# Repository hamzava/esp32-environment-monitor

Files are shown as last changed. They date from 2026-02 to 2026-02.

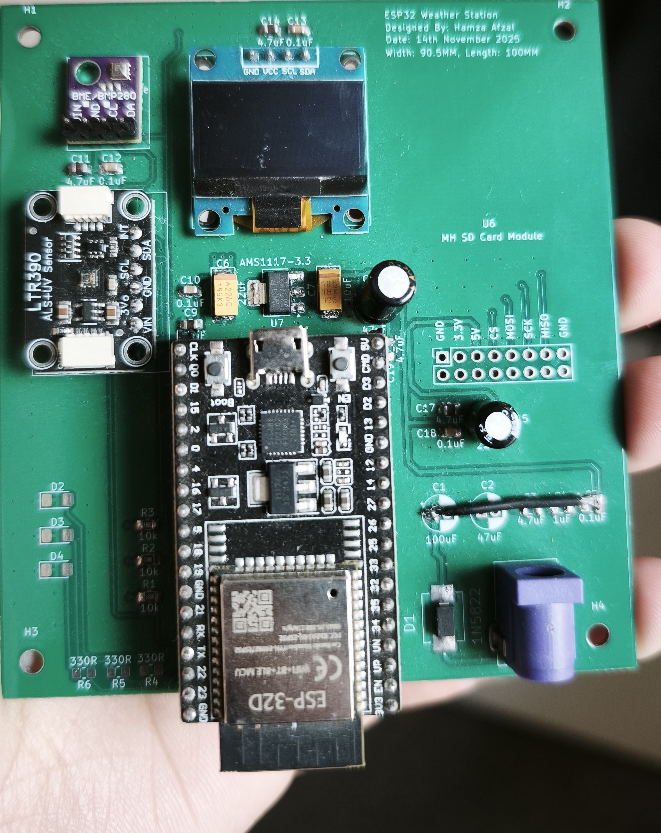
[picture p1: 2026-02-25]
Hardware/Project_Media/Prototype.jpg

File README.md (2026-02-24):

# 🌱 ESP32 Environment Monitoring System
### Using ESP32 + ESP-IDF + I2C Sensors

🟢 This project represents an exploration into embedded firmware architecture, multi layer hardware design, and communication protocol integration using the ESP32 platform and the ESP-IDF framework.

## ◆ Project Overview

🟥 This project is a Environment Monitor prototype built using:

 - ESP-32 & ESP-IDF
 - BME280 Atmosphere Sensor
 - LTR390 UV Sensor

🟥 The objective was to to acquire environmental data from digital sensors and prepare it for network-based transmission.

This prototype is focused on:

✔ Multi-layer PCB & hardware design  </br>
✔ ESP-IDF firmware development </br>
✔ Peripheral communication via I2C </br>
✔ Power supply and regulation </br>

## ◆ Current Status:
- Fully operational Embedded System from working 4 layer PCB to a running ESP-IDF Super Loop

## ◆ Project Aims & Development Roadmap <br />
- This project was structured around incremental, demonstrable milestones, rather than a single monolithic goal.

## ✅ Completed / Implemented: 
🟢 Completely Functional 4-Layer PCB <br />
🟢 A running ESP-IDF based super loop <br />

## 🚧 In Progress / Planned Enhancements
🟡 Migration to FreeRTOS-Based Architecture <br />
🟡 WiFi Integration & MQTT Communication <br />

## ◆ Repository Structure
/Docs
 ├── Datasheets

/Hardware
 ├── Gerbers
 ├── Project_Media
 ├── Schematic & PCB

 /Firmware

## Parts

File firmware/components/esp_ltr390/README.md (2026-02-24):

# Lite-On LTR390UV Sensor

License: MIT

[![Build with PlatformIO](https://img.shields.io/badge/build%20with-PlatformIO-orange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)](https://platformio.org/)



This ESP32 espressif IoT development framework (esp-idf) i2c peripheral driver was developed for the Lite-On LTR390UV I2C sensor.  Information on features and functionality are documented and can be found in the `ltr390uv.h` header file and in the `documentation` folder.

## Repository

The component is hosted on github and is located here: <https://github.com/K0I05/ESP32-S3_ESP-IDF_COMPONENTS/tree/main/components/peripherals/i2c/esp_ltr390uv>

## General Usage

To get started, simply copy the component to your project's `components` folder and reference the `ltr390uv.h` header file as an include.  The component includes documentation for the peripheral such as the datasheet, application notes, and/or user manual where applicable.

```text
components
└── esp_ltr390uv
    ├── CMakeLists.txt
    ├── README.md
    ├── LICENSE
    ├── idf_component.yml
    ├── library.json
    ├── documentation
    │   └── datasheets, etc.
    ├── include
    │   └── ltr390uv_version.h
    │   └── ltr390uv.h
    └── ltr390uv.c
```

## Basic Example

Once a driver instance is instantiated the sensor is ready for usage as shown in the below example.   This basic implementation of the driver utilizes default configuration settings and makes a measurement request from the sensor at user defined interval and prints the results.

```c
#include <ltr390uv.h>

void i2c0_ltr390uv_task( void *pvParameters ) {
    // initialize the xLastWakeTime variable with the current time.
    TickType_t         last_wake_time   = xTaskGetTickCount ();
    //
    // initialize i2c device configuration
    ltr390uv_config_t dev_cfg          = I2C_LTR390UV_CONFIG_DEFAULT;
    ltr390uv_handle_t dev_hdl;
    //
    // init device
    ltr390uv_init(i2c0_bus_hdl, &dev_cfg, &dev_hdl);
    if (dev_hdl == NULL) {
        ESP_LOGE(APP_TAG, "ltr390uv handle init failed");
        assert(dev_hdl);
    }
    //
    ltr390uv_control_register_t c_reg;
    ltr390uv_interrupt_config_register_t ic_reg;
    ltr390uv_measure_register_t m_reg;
    ltr390uv_gain_register_t    g_reg;
    //
    /* attempt i2c read transaction */
    ltr390uv_get_measure_register(dev_hdl, &m_reg);
    ltr390uv_get_gain_register(dev_hdl, &g_reg);
    ltr390uv_get_interrupt_config_register(dev_hdl, &ic_reg);
    ltr390uv_get_control_register(dev_hdl, &c_reg);
    //
    ESP_LOGI(APP_TAG, "Control Register (0x%02x): %s", c_reg.reg, uint8_to_binary(c_reg.reg));
    ESP_LOGI(APP_TAG, "Measure Register (0x%02x): %s", m_reg.reg, uint8_to_binary(m_reg.reg));
    ESP_LOGI(APP_TAG, "Gain Register    (0x%02x): %s", g_reg.reg, uint8_to_binary(g_reg.reg));
    ESP_LOGI(APP_TAG, "IRQ Cfg Register (0x%02x): %s", ic_reg.reg, uint8_to_binary(ic_reg.reg));
    //
    // task loop entry point
    for ( ;; ) {
        ESP_LOGI(APP_TAG, "######################## LTR390UV - START #########################");
        //
        // handle sensor
        
        float ambient_light; 
        esp_err_t result = ltr390uv_get_ambient_light(dev_hdl, &ambient_light);
        if(result != ESP_OK) {
            ESP_LOGE(APP_TAG, "ltr390uv device read failed (%s)", esp_err_to_name(result));
        } else {
            ESP_LOGI(APP_TAG, "ambient light:     %.2f Lux", ambient_light);
        }

        uint32_t sensor_counts;
        result = ltr390uv_get_als(dev_hdl, &sensor_counts);
        if(result != ESP_OK) {
            ESP_LOGE(APP_TAG, "ltr390uv device read failed (%s)", esp_err_to_name(result));
        } else {
            ESP_LOGI(APP_TAG, "als sensor counts: %lu", sensor_counts);
        }

        float uvi;
        result = ltr390uv_get_ultraviolet_index(dev_hdl, &uvi);
        if(result != ESP_OK) {
            ESP_LOGE(APP_TAG, "ltr390uv device read failed (%s)", esp_err_to_name(result));
        } else {
            ESP_LOGI(APP_TAG, "ultraviolet index: %f", uvi);
        }

        result = ltr390uv_get_uvs(dev_hdl, &sensor_counts);
        if(result != ESP_OK) {
            ESP_LOGE(APP_TAG, "ltr390uv device read failed (%s)", esp_err_to_name(result));
        } else {
            ESP_LOGI(APP_TAG, "uvs sensor counts: %lu", sensor_counts);
        }
        //
        ESP_LOGI(APP_TAG, "######################## LTR390UV - END ###########################");
        //
        //
        // pause the task per defined wait period
        vTaskDelaySecUntil( &last_wake_time, I2C0_TASK_SAMPLING_RATE );
    }
    //
    // free resources
    ltr390uv_delete( dev_hdl );
    vTaskDelete( NULL );
}
```

Copyright (c) 2024 Eric Gionet (<gionet.c.eric@gmail.com>)

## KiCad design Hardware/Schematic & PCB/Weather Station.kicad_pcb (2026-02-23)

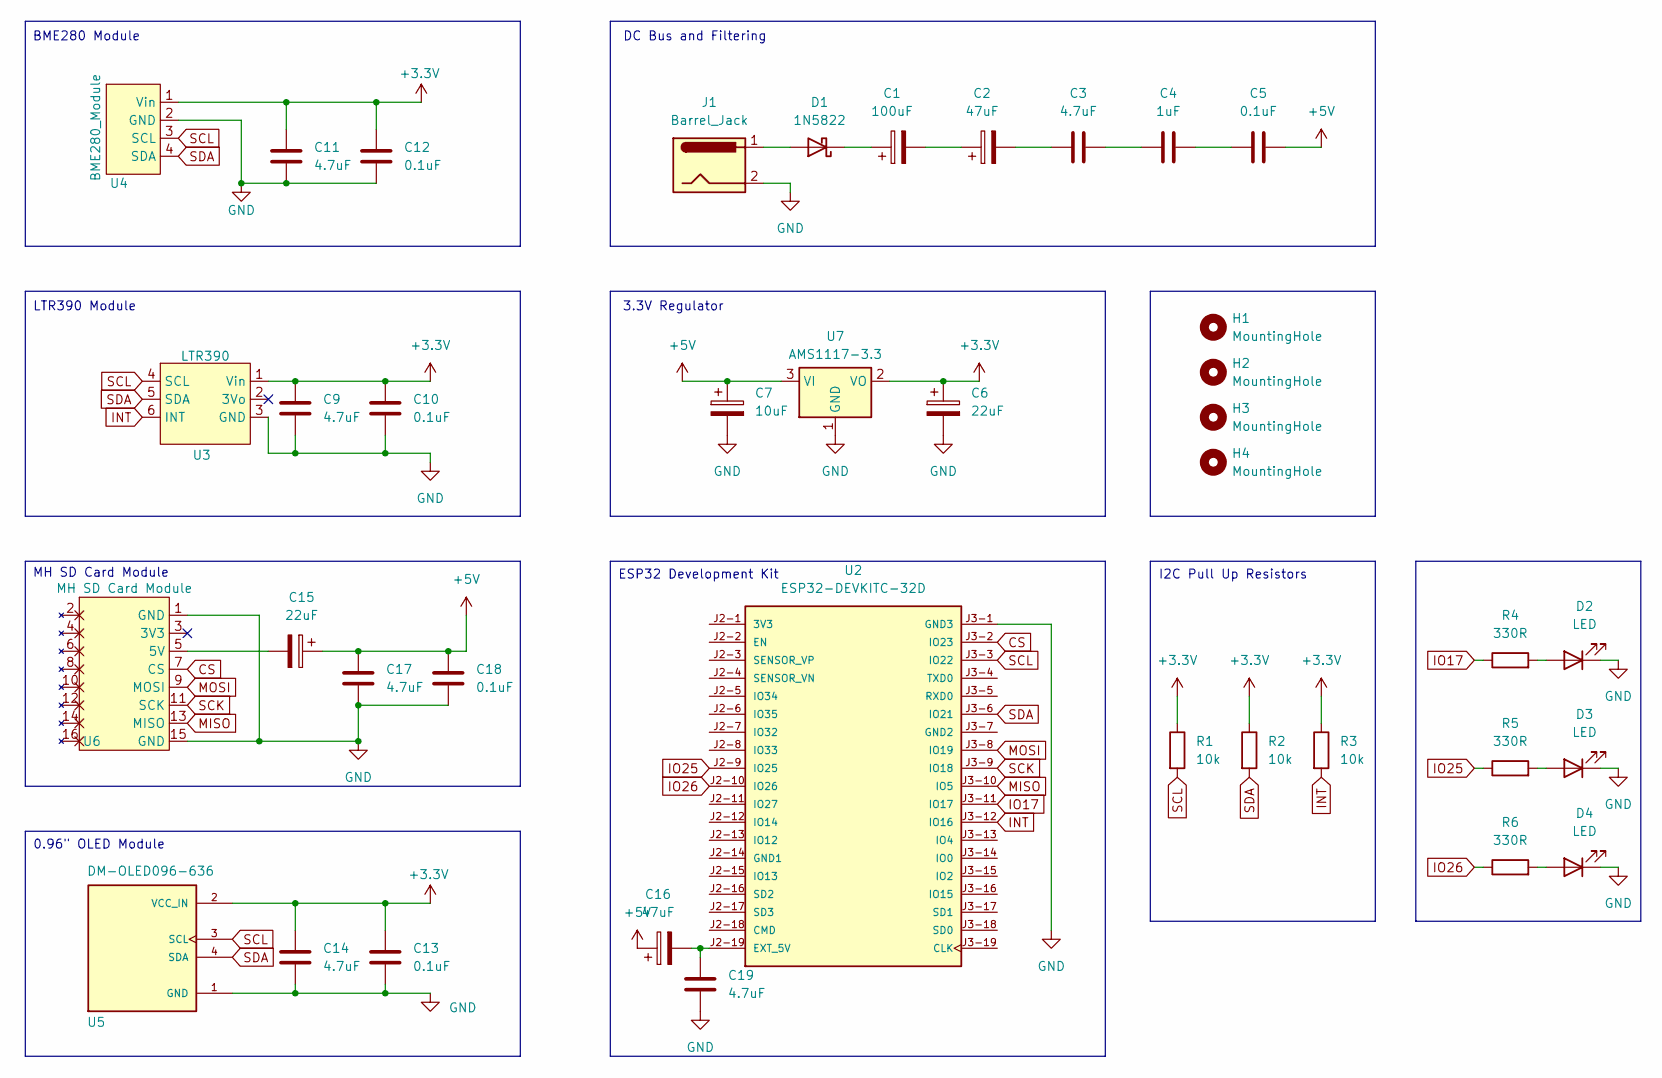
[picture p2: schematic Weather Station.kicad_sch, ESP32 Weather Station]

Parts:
C1: 100uF; CP_Radial_D5.0mm_P2.00mm
C2, C16: 47uF; CP_Radial_D5.0mm_P2.00mm
C3, C9, C11, C14, C17, C19: 4.7uF; C_0805_2012Metric_Pad1.18x1.45mm_HandSolder
C4: 1uF; C_0805_2012Metric_Pad1.18x1.45mm_HandSolder
C5, C10, C12, C13, C18: 0.1uF; C_0805_2012Metric_Pad1.18x1.45mm_HandSolder
C6: 22uF; CP_EIA-6032-28_Kemet-C_HandSolder
C7: 10uF; CP_EIA-6032-28_Kemet-C_HandSolder
C15: 22uF; CP_Radial_D5.0mm_P2.00mm
D1: 1N5822; SS34
D2, D3, D4: LED; LED_1206_3216Metric_Pad1.42x1.75mm_HandSolder
H1, H2, H3, H4: MountingHole; MountingHole_3.2mm_M3
J1: Barrel_Jack; BarrelJack_Wuerth_6941xx301002
R1, R2, R3: 10k; R_0805_2012Metric_Pad1.20x1.40mm_HandSolder
R4, R5, R6: 330R; R_0805_2012Metric_Pad1.20x1.40mm_HandSolder
U2: ESP32-DEVKITC-32D; PARTREV V4
U3: LTR390
U4: BME280_Module; BME 280 Module
U5: DM-OLED096-636; MODULE_DM-OLED096-636; PARTREV 2018-09-10
U6: MH SD Card Module; MH-SD_Card Module
U7: AMS1117-3.3; SOT-223-3_TabPin2

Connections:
+3.3V: C6.1, C9.2, C10.2, C11.2, C12.2, C13.2, C14.2, R1.1, R2.1, R3.1, U3.1 (Vin), U4.1 (Vin), U5.2 (VCC_IN), U7.2 (VO)
+5V: C5.2, C7.1, C15.1, C16.1, C17.2, C18.2, U7.3 (VI)
CS: U2.J3-2 (IO23), U6.7 (CS)
GND: C6.2, C7.2, C9.1, C10.1, C11.1, C12.1, C13.1, C14.1, C17.1, C18.1, C19.1, D2.1 (K), D3.1 (K), D4.1 (K), J1.2, U2.J3-1 (GND3), U3.3 (GND), U4.2 (GND), U5.1 (GND), U6.1 (GND), U6.15 (GND), U7.1 (GND)
INT: R3.2, U2.J3-12 (IO16), U3.6 (INT)
IO17: R4.1, U2.J3-11 (IO17)
IO25: R5.1, U2.J2-9 (IO25)
IO26: R6.1, U2.J2-10 (IO26)
MISO: U2.J3-10 (IO5), U6.13 (MISO)
MOSI: U2.J3-8 (IO19), U6.9 (MOSI)
unnamed: C1.2, C2.1
unnamed: C2.2, C3.1
unnamed: C3.2, C4.1
unnamed: C4.2, C5.1
unnamed: D1.2 (A), J1.1
unnamed: C1.1, D1.1 (K)
unnamed: D2.2 (A), R4.2
unnamed: D3.2 (A), R5.2
unnamed: D4.2 (A), R6.2
unnamed: C16.2, C19.2, U2.J2-19 (EXT_5V)
unnamed: C15.2, U6.5 (5V)
SCK: U2.J3-9 (IO18), U6.11 (SCK)
SCL: R1.2, U2.J3-3 (IO22), U3.4 (SCL), U4.3 (SCL), U5.3 (SCL)
SDA: R2.2, U2.J3-6 (IO21), U3.5 (SDA), U4.4 (SDA), U5.4 (SDA)

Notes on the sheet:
I2C Pull Up Resistors
LTR390 Module
3.3V Regulator
BME280 Module
ESP32 Development Kit
DC Bus and Filtering
MH SD Card Module
0.96" OLED Module

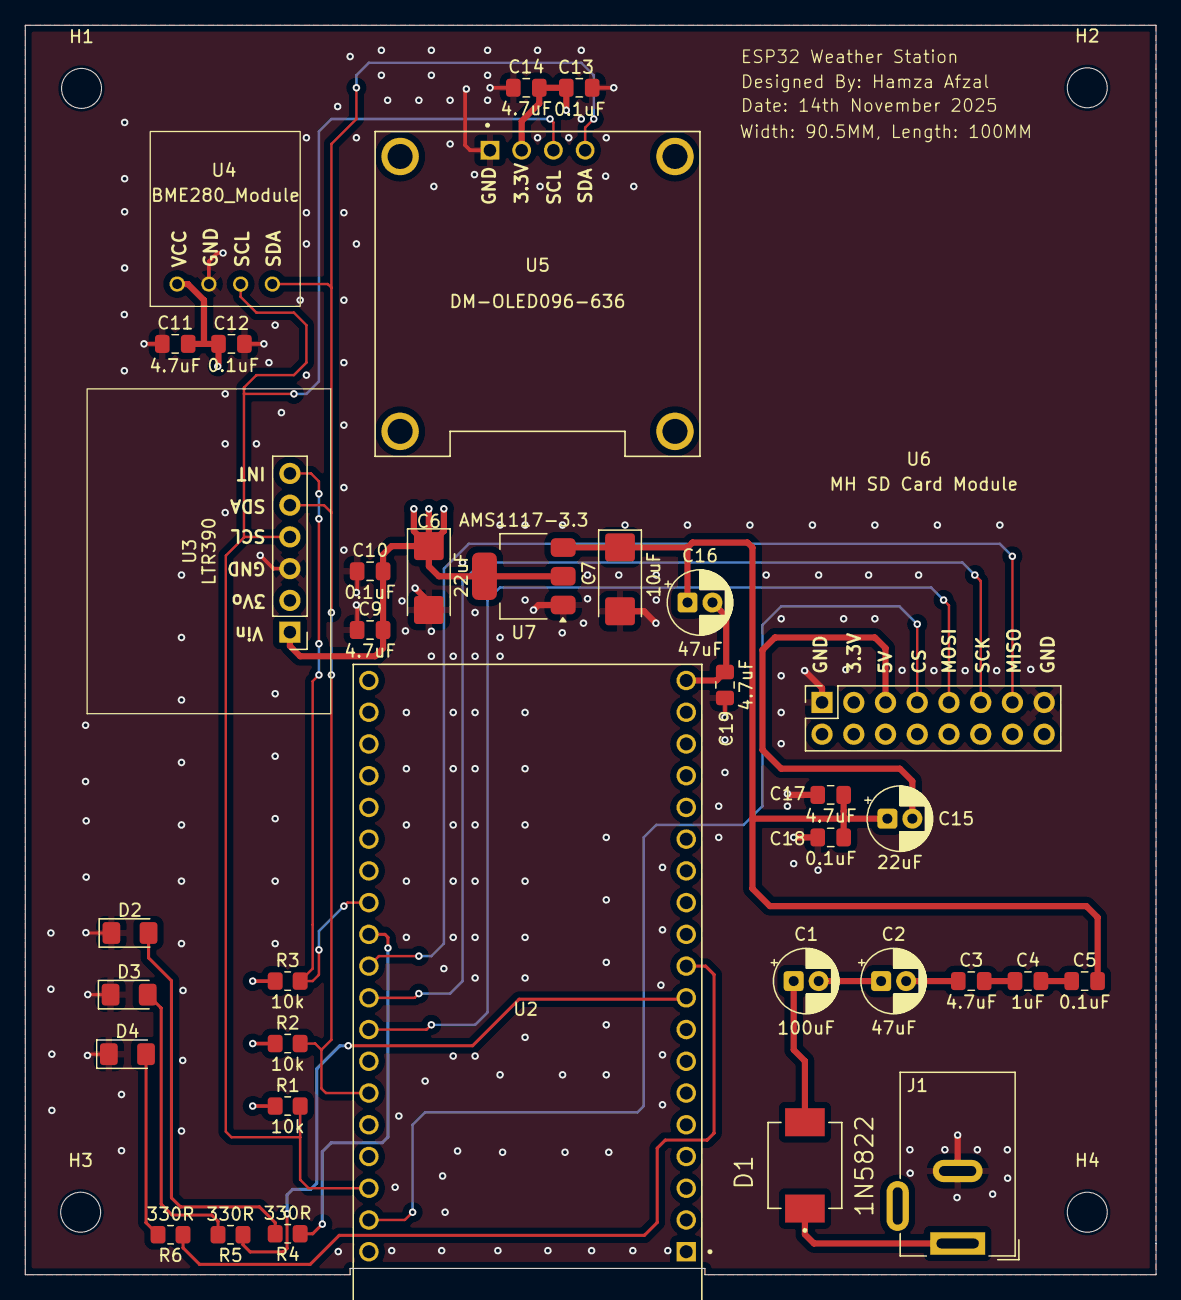
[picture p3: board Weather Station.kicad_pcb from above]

Board: 4 copper layers, 90.5 x 100.0 mm, 39 parts (0 on the bottom side), 24 nets.

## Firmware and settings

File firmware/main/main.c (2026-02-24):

#include <stdio.h>
#include "driver/i2c_master.h"
#include "freertos/FreeRTOS.h"
#include "freertos/task.h"
#include "esp_log.h"
#include "bme280_defs.h"
#include "bme280_wrapper.h"
#include "ssd1306.h"
#include "ssd1306_wrapper.h"
#include "i2c.h"
#include "ltr390_wrapper.h"
#include "ltr390uv.h"
#include "driver/gpio.h"


#define I2C_SDA         21
#define I2C_SCL         22

static const char *TAG_APP = "APP";

void app_main(void)
{    

    i2c_init(); 

    i2c_scan();

    ESP_LOGI(TAG_APP, "Starting Application");

    bme280_i2c_init();

    bme280_i2c_config_and_init();

    bme280_settings(BME280_POWERMODE_NORMAL);
    
    bme280_values_t bme_values;

    ltr390_cfg_and_init();

    ltr390_values_t ltr390_values;
  
    ssd1306_cfg_and_init();

    test_display();

    while (1)
    {      
        
        bme280_read_values(&bme_values);

        ESP_LOGI(TAG_APP, "Temp: %.1fC, Hum: %.1f%%, Pres: %.1fhPa",
        bme_values.temperature_c,
        bme_values.humidity_pct,
        bme_values.pressure_hpa);

        display_weather_data(bme_values.temperature_c, bme_values.humidity_pct, bme_values.pressure_hpa);
       
        ltr390_data(&ltr390_values);

        ESP_LOGI(TAG_APP, "Ambient Light:%.2f, UV Index:%.2f",
        ltr390_values.ambient_light,
        ltr390_values.ultraviolet_index);
        
        display_ltr390_data(ltr390_values.ambient_light, ltr390_values.ultraviolet_index);
        

        
    }

}
    


          
    
 

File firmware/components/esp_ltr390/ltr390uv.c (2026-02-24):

/*
 * The MIT License (MIT)
 *
 * Copyright (c) 2024 Eric Gionet (gionet.c.eric@gmail.com)
 *
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
 * THE SOFTWARE IS PROVIDED "AS IS", WITHOUT WARRANTY OF ANY KIND, EXPRESS OR
 * IMPLIED, INCLUDING BUT NOT LIMITED TO THE WARRANTIES OF MERCHANTABILITY,
 * FITNESS FOR A PARTICULAR PURPOSE AND NONINFRINGEMENT. IN NO EVENT SHALL THE
 * AUTHORS OR COPYRIGHT HOLDERS BE LIABLE FOR ANY CLAIM, DAMAGES OR OTHER
 * LIABILITY, WHETHER IN AN ACTION OF CONTRACT, TORT OR OTHERWISE, ARISING FROM,
 * OUT OF OR IN CONNECTION WITH THE SOFTWARE OR THE USE OR OTHER DEALINGS IN THE
 * SOFTWARE.
 */

/**
 * @file ltr390uv.c
 *
 * ESP-IDF driver for LTR390UV sensor
 *
 * Ported from esp-open-rtos
 *
 * Copyright (c) 2024 Eric Gionet (gionet.c.eric@gmail.com)
 *
 * MIT Licensed as described in the file LICENSE
 */
#include "include/ltr390uv.h"
#include <string.h>
#include <stdio.h>
#include <math.h>
#include <esp_log.h>
#include <esp_check.h>
#include <esp_timer.h>
#include <freertos/FreeRTOS.h>
#include <freertos/task.h>

/*
 * LTR390UV definitions
 */

#define LTR390UV_REG_MAIN_CTRL_RW       UINT8_C(0x00) /* 0x00 */
#define LTR390UV_REG_ALS_UVS_MEAS_RW    UINT8_C(0x04)
#define LTR390UV_REG_ALS_UVS_GAIN_RW    UINT8_C(0x05)
#define LTR390UV_REG_PART_ID_R          UINT8_C(0x06)
#define LTR390UV_REG_MAIN_STS_R         UINT8_C(0x07)

#define LTR390UV_REG_ALS_DATA_0_R       UINT8_C(0x0D) /* LSB */
#define LTR390UV_REG_ALS_DATA_1_R       UINT8_C(0x0E)
#define LTR390UV_REG_ALS_DATA_2_R       UINT8_C(0x0F) /* MSB */

#define LTR390UV_REG_UVS_DATA_0_R       UINT8_C(0x10) /* LSB */
#define LTR390UV_REG_UVS_DATA_1_R       UINT8_C(0x11)
#define LTR390UV_REG_UVS_DATA_2_R       UINT8_C(0x12) /* MSB */

#define LTR390UV_REG_INT_CFG_RW         UINT8_C(0x19)
#define LTR390UV_REG_INT_PST_RW         UINT8_C(0x1A)

#define LTR390UV_REG_ALS_THRES_UP_0_RW  UINT8_C(0x21) /* LSB */
#define LTR390UV_REG_ALS_THRES_UP_1_RW  UINT8_C(0x22)
#define LTR390UV_REG_ALS_THRES_UP_2_RW  UINT8_C(0x23) /* MSB */

#define LTR390UV_REG_ALS_THRES_LO_0_RW  UINT8_C(0x24) /* LSB */
#define LTR390UV_REG_ALS_THRES_LO_1_RW  UINT8_C(0x25)
#define LTR390UV_REG_ALS_THRES_LO_2_RW  UINT8_C(0x26) /* MSB */

#define LTR390UV_SENSITIVITY_MAX        (2300.0f)       /* see datasheet, section 4.5 */
#define LTR390UV_INTEGRATION_TIME_MAX   (4.0f * 100.0f) /* I2C_LTR390UV_SR_20BIT */
#define LTR390UV_GAIN_MAX               (18.0f)         /* I2C_LTR390UV_MG_X18 */

#define LTR390UV_DATA_POLL_TIMEOUT_MS  UINT16_C(500)
#define LTR390UV_DATA_READY_DELAY_MS   UINT16_C(2)
#define LTR390UV_POWERUP_DELAY_MS      UINT16_C(120)
#define LTR390UV_RESET_DELAY_MS        UINT16_C(25)
#define LTR390UV_WAKEUP_DELAY_MS       UINT16_C(15)
#define LTR390UV_APPSTART_DELAY_MS     UINT16_C(10)    /*!< ltr390uv delay after initialization before application start-up */
#define LTR390UV_CMD_DELAY_MS          UINT16_C(5)     /*!< ltr390uv delay before attempting I2C transactions after a command is issued */
#define LTR390UV_TX_RX_DELAY_MS        UINT16_C(10)    /*!< ltr390uv delay after attempting an I2C transmit transaction and attempting an I2C receive transaction */


/*
 * macro definitions
*/
#define ESP_TIMEOUT_CHECK(start, len) ((uint64_t)(esp_timer_get_time() - (start)) >= (len))
#define ESP_ARG_CHECK(VAL) do { if (!(VAL)) return ESP_ERR_INVALID_ARG; } while (0)

/*
* static constant declarations
*/
static const char *TAG = "ltr390uv";


/**
 * @brief LTR390UV I2C write byte to register address transaction.
 * 
 * @param handle LTR390UV device handle.
 * @param reg_addr LTR390UV register address to write to.
 * @param byte LTR390UV write transaction input byte.
 * @return esp_err_t ESP_OK on success.
 */
static inline esp_err_t ltr390uv_i2c_write_byte_to(ltr390uv_handle_t handle, uint8_t reg_addr, const uint8_t byte) {
    const bit16_uint8_buffer_t tx = { reg_addr, byte };

    /* validate arguments */
    ESP_ARG_CHECK( handle );

    /* attempt i2c write transaction */
    ESP_RETURN_ON_ERROR( i2c_master_transmit(handle->i2c_handle, tx, BIT16_UINT8_BUFFER_SIZE, I2C_XFR_TIMEOUT_MS), TAG, "i2c_master_transmit, i2c write failed" );
                        
    return ESP_OK;
}

/**
 * @brief LTR390UV I2C read from register address transaction.  This is a write and then read process.
 * 
 * @param handle LTR390UV device handle.
 * @param reg_addr LTR390UV register address to read from.
 * @param buffer LTR390UV read transaction return buffer.
 * @param size Length of buffer to store results from read transaction.
 * @return esp_err_t ESP_OK on success.
 */
static inline esp_err_t ltr390uv_i2c_read_from(ltr390uv_handle_t handle, const uint8_t reg_addr, uint8_t *buffer, const uint8_t size) {
    const bit8_uint8_buffer_t tx = { reg_addr };

    /* validate arguments */
    ESP_ARG_CHECK( handle );

    ESP_RETURN_ON_ERROR( i2c_master_transmit_receive(handle->i2c_handle, tx, BIT8_UINT8_BUFFER_SIZE, buffer, size, I2C_XFR_TIMEOUT_MS), TAG, "ltr390uv_i2c_read_from failed" );

    return ESP_OK;
}

/**
 * @brief LTR390UV I2C read byte from register address transaction.
 * 
 * @param handle LTR390UV device handle.
 * @param reg_addr LTR390UV register address to read from.
 * @param byte LTR390UV read transaction return byte.
 * @return esp_err_t ESP_OK on success.
 */
static inline esp_err_t ltr390uv_i2c_read_byte_from(ltr390uv_handle_t handle, const uint8_t reg_addr, uint8_t *const byte) {
    const bit8_uint8_buffer_t tx = { reg_addr };
    bit8_uint8_buffer_t rx = { 0 };

    /* validate arguments */
    ESP_ARG_CHECK( handle );

    ESP_RETURN_ON_ERROR( i2c_master_transmit_receive(handle->i2c_handle, tx, BIT8_UINT8_BUFFER_SIZE, rx, BIT8_UINT8_BUFFER_SIZE, I2C_XFR_TIMEOUT_MS), TAG, "ltr390uv_i2c_read_byte_from failed" );

    /* set output parameter */
    *byte = rx[0];

    return ESP_OK;
}

/**
 * @brief LTR390UV I2C write transaction.
 * 
 * @param handle LTR390UV device handle.
 * @param buffer Buffer to write for write transaction.
 * @param size Length of buffer to write for write transaction.
 * @return esp_err_t ESP_OK on success.
 */
static inline esp_err_t ltr390uv_i2c_write(ltr390uv_handle_t handle, const uint8_t *buffer, const uint8_t size) {
    /* validate arguments */
    ESP_ARG_CHECK( handle );

    /* attempt i2c write transaction */
    ESP_RETURN_ON_ERROR( i2c_master_transmit(handle->i2c_handle, buffer, size, I2C_XFR_TIMEOUT_MS), TAG, "i2c_master_transmit, i2c write failed" );
                        
    return ESP_OK;
}
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
